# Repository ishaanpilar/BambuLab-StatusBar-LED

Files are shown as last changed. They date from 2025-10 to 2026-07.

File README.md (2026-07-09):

# Bambu Status Bar

**Version 2.0** — a full rewrite of the original firmware and repo
structure. See [CHANGELOG.md](CHANGELOG.md) for what changed.

A compact, ESP32-powered LED status bar for Bambu Lab 3D printers, with an
integrated purge-line holder — printed as one piece.

Real-time visual feedback for what the printer is doing: connecting,
homing/leveling, heating (with a live temperature-progress bar), printing
(with a live progress bar), paused, finished, or in an error state — all
read straight from the printer's own local MQTT status stream.

## Compatible printers

Any Bambu Lab printer with **LAN Mode (Developer Mode)** enabled:
X1 / X1C / X1E, P1P / P1S, A1 / A1 mini, H2D.

## Key features

- Visual states: WiFi/MQTT connecting, homing, bed leveling, nozzle
  heating, print progress, paused, finished, error (HMS)
- No hardcoded WiFi or printer credentials — first boot opens a setup
  portal (see [firmware/README.md](firmware/README.md))
- Single ESP32, short WS2812 LED strip, USB-powered from the printer's rear
  USB port
- [Flash straight from your browser](https://ishaanpilar.github.io/BambuLab-StatusBar-LED/) —
  no PlatformIO or Arduino IDE required
- Integrated purge-line holder, single-piece diagonal print
- PlatformIO firmware (with an Arduino IDE-compatible mirror) and a native
  unit-test suite for the core status logic
- Open source — contributions welcome

## Repo layout

```text
firmware/       ESP32 firmware (PlatformIO + Arduino IDE), unit tests
hardware/       3D print file, BOM, wiring/assembly docs
web-installer/  Browser-based flashing page (ESP Web Tools)
docs/           Troubleshooting and setup notes
```

## Quick start

1. Print [`hardware/PrintStatusBar_with_PurgeHolder.3mf`](hardware/PrintStatusBar_with_PurgeHolder.3mf)
   and wire it up — see [hardware/README.md](hardware/README.md).
2. Flash the firmware. Two options:
   - **Easiest:** plug the ESP32 into your computer and use the
     [browser installer](https://ishaanpilar.github.io/BambuLab-StatusBar-LED/)
     (Chrome/Edge desktop) — no software install needed.
   - **If you want to modify the firmware:** see
     [firmware/README.md](firmware/README.md) for PlatformIO/Arduino IDE
     instructions.
3. On first boot, connect to the `BambuStatusBar-Setup` WiFi network and
   fill in your WiFi + printer details in the captive portal.
4. Power it from your printer's internal USB port and mount it.

Having trouble? See [docs/troubleshooting.md](docs/troubleshooting.md).

## License

MIT — see [LICENSE](LICENSE)

## Contributing

Read [CONTRIBUTING.md](CONTRIBUTING.md). Issues and PRs welcome.

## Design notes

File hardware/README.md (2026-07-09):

# Hardware

A single-piece printed status bar with an integrated purge-line holder,
lit by a short WS2812 LED strip and driven by an ESP32.

## Parts

See [BOM.md](BOM.md).

## Print

- Model: [`PrintStatusBar_with_PurgeHolder.3mf`](PrintStatusBar_with_PurgeHolder.3mf)
- Prints diagonally in one go — no supports needed with the orientation
  baked into the file.
- Any 0.2mm-profile PLA/PETG print settings work; nothing exotic required.

## Wiring

| WS2812 strip pin | ESP32 |
|---|---|
| 5V | 5V (or VIN, if powering from the printer's USB) |
| GND | GND |
| DIN (data) | GPIO 5 (default — see `hw::kDataPin` in [`firmware/src/Config.h`](../firmware/src/Config.h)) |

- Default LED count is 13, matching the printed channel. If you resize the
  strip, update `hw::kNumLeds` in `firmware/src/Config.h` and reflash.
- The firmware caps LED draw at 850mA via `FastLED.setMaxPowerInMilliWatts`
  (`hw::kMaxMilliwatts`) so it stays within what a printer's rear USB port
  can safely supply — raise this only if you're powering the ESP32 from a
  separate supply rated for it.

## Assembly

1. Print the model and thread the LED strip into the channel, DIN end
   toward the ESP32.
2. Mount the ESP32 in the base — either M3 heat-set inserts + M3x6 screws,
   or double-sided tape.
3. Route the LED wires through the top hole to the ESP32.
4. Power the ESP32 from the printer's rear USB port with a short
   USB‑A → Micro‑USB/USB‑C cable.

See [`firmware/README.md`](../firmware/README.md) for flashing and
first-boot setup.

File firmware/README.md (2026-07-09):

# Firmware

ESP32 firmware that subscribes to a Bambu Lab printer's local (LAN-mode)
MQTT status stream and drives a WS2812 LED bar to reflect what it's doing —
connecting, heating, printing (with progress), paused, finished, or in an
error state.

Compatible with Bambu Lab's LAN-mode MQTT printers: X1/X1C/X1E, P1P/P1S,
A1/A1 mini, and H2D. LAN Mode (a.k.a. Developer Mode) must be enabled on the
printer — see [docs/troubleshooting.md](../docs/troubleshooting.md).

## Structure

- `src/` — the firmware, as a PlatformIO project (source of truth).
  - `main.cpp` — wiring/`setup()`/`loop()`.
  - `Config.h` — compile-time hardware config (LED pin/count/brightness).
  - `Provisioning.{h,cpp}` — WiFiManager captive portal + NVS storage for
    WiFi and printer identity (IP, serial, access code) — no secrets in
    source, no recompiling per printer.
  - `BambuMqttClient.{h,cpp}` — MQTT connect/reconnect/subscribe.
  - `PrinterState.{h,cpp}` — pure state-machine: MQTT payload → LED state +
    progress. No hardware dependency; unit tested (see below).
  - `LedController.{h,cpp}` — FastLED animations per state.
- `test/test_printer_state.cpp` — host-side unit tests for `PrinterState`.
- `arduino-ide/BambuStatusBar/BambuStatusBar.ino` — generated single-file
  mirror of `src/` for Arduino IDE users. Don't edit it directly — see
  below.
- `tools/generate_arduino_sketch.py` — regenerates the `.ino` mirror.

## Option A: PlatformIO (recommended)

1. [Install PlatformIO](https://platformio.org/install) (CLI or the VS Code
   extension).
2. From `firmware/`:
   ```
   pio run -e esp32dev          # build
   pio run -e esp32dev -t upload  # build + flash (board connected via USB)
   pio device monitor -b 115200   # serial log
   ```
3. Run the unit tests any time with `pio test -e native` (no hardware
   needed).

## Option B: Arduino IDE

1. Install the ESP32 board package and these libraries via Library
   Manager: **FastLED**, **PubSubClient**, **ArduinoJson** (v7), **WiFiManager**
   (by tzapu).
2. Open `arduino-ide/BambuStatusBar/BambuStatusBar.ino`.
3. Select your ESP32 board, then Upload.

If you change anything under `src/`, regenerate the mirror before
committing:
```
python3 tools/generate_arduino_sketch.py
```
CI fails the build if the mirror drifts from `src/`.

## First boot / setup

No credentials are hardcoded. On first boot (or after holding the BOOT
button for 3s at power-on), the ESP32 opens a WiFi access point named
`BambuStatusBar-Setup` with a captive portal to enter:

- Your WiFi network + password
- The printer's IP address
- The printer's serial number
- The printer's LAN-mode access code

These are saved to the ESP32's flash (NVS) and reused on every subsequent
boot. See [docs/troubleshooting.md](../docs/troubleshooting.md) for where to
find each of these on the printer, and what to check if it won't connect.

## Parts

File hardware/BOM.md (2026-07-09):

# Bill of Materials

| Qty | Part | Notes |
|-----|---|---|
| 1 | ESP32 dev board | e.g. ESP32 DevKit V1 (any dev board with a free GPIO + 5V/GND works) |
| 1 | WS2812 / WS2812B LED strip | 13 LEDs at the strip's native pitch, or trim/extend and update `NUM_LEDS` in firmware config |
| 1 | USB-A → Micro-USB or USB-C cable, short | Powers the ESP32 from the printer's rear USB port |
| 4 | M3 heat-set inserts | Optional — for a removable/serviceable mount |
| 4 | M3x6 screws | Optional, pairs with the heat-set inserts |
| — | Double-sided tape | Alternative to heat-set inserts for mounting |

See [README.md](README.md) for wiring and assembly.

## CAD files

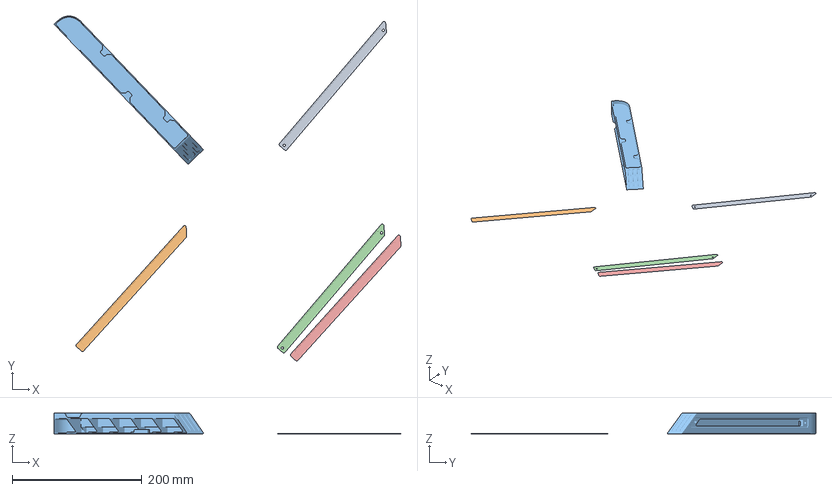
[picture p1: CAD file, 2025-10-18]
hardware/PrintStatusBar_with_PurgeHolder.3mf
534.2 x 531.2 x 32.0 mm
Diffuser.stl x 2
Diffuser No Holes.stl x 2
Purge Tray v6.stl

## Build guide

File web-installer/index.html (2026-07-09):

# Bambu Status Bar

Flash the firmware to your ESP32 straight from this page — no PlatformIO, no Arduino IDE, no config files to edit.

## 1. Connect your ESP32

Plug the ESP32 into this computer with a USB cable (the same one you'll use to power it from the printer works fine).

## 2. Install

Your browser doesn't support Web Serial. Open this page in Chrome or Edge on a desktop computer instead — Web Serial isn't available in Firefox, Safari, or on mobile. This page needs to be served over HTTPS (or localhost) to access USB devices. If you're seeing this on the published site, please open an issue (https://github.com/ishaanpilar/BambuLab-StatusBar-LED/issues). Works in Chrome / Edge on desktop.

## 3. Finish setup over WiFi

Once flashing completes, the ESP32 reboots and opens its own WiFi network to configure itself — no cables needed for this part:

1. On your phone or laptop, join the WiFi network named BambuStatusBar-Setup.
2. A setup page should open automatically (a "captive portal"). If it doesn't, open a browser and go to 192.168.4.1.
3. Enter your home WiFi details, plus your printer's IP address, serial number, and LAN access code, then save.

Not sure where to find your printer's IP/serial/access code, or the setup page isn't showing up? See the troubleshooting guide (https://github.com/ishaanpilar/BambuLab-StatusBar-LED/blob/main/docs/troubleshooting.md).

Want to modify the firmware instead? See the PlatformIO / Arduino IDE instructions (https://github.com/ishaanpilar/BambuLab-StatusBar-LED/blob/main/firmware/README.md) in the repo. · Bambu Status Bar on GitHub (https://github.com/ishaanpilar/BambuLab-StatusBar-LED)

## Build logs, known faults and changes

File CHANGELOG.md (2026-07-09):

# Changelog

## 2.0.0

Full rewrite of the original firmware and repo structure.

- Merged the two divergent original sketches (`Main_Progressbar_v5_web.ino`,
  `Main_Src_v4.ino`) into a single, defensively-parsed state machine
  (`firmware/src/PrinterState.cpp`) covering all Bambu Lab LAN-mode printers
  (X1/X1C/X1E, P1P/P1S, A1/A1 mini, H2D).
- Fixed: heating-progress bar was hardcoded to a 40–200°C range and broke on
  high-temp filaments (ABS/PC/PA); now scales to the printer's actual
  reported target temperature.
- Fixed: an MQTT buffer-size bug that could silently truncate large status
  payloads.
- Fixed: the ERROR (HMS) LED state had no way to recover once triggered;
  added proper recovery + same-packet hysteresis.
- Removed all hardcoded WiFi/MQTT credentials — first boot now opens a
  WiFiManager captive portal to configure WiFi and printer identity, no
  recompiling per printer.
- Added a native unit-test suite for the status logic (`pio test -e native`)
  and CI that builds the real firmware on every push.
- Added a browser-based installer (`web-installer/`, powered by ESP Web
  Tools) — flash over USB with no PlatformIO/Arduino IDE install required.
- Restructured the repo into `firmware/`, `hardware/`, `docs/`,
  `web-installer/` with docs that match reality.

## 1.x

The original, hand-built firmware — two independent Arduino sketches with
hardcoded credentials, still visible in git history prior to the 2.0.0
rewrite.

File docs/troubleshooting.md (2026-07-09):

# Troubleshooting

## Enabling LAN mode on the printer

This firmware talks to the printer's **local** MQTT broker over LAN — it
never touches Bambu's cloud. Every Bambu Lab printer needs this turned on
first:

1. On the printer's touchscreen: **Settings → Network → LAN Only Mode** (some
   firmware calls this **Developer Mode**) → enable it.
2. Once enabled, the screen shows an **Access Code** and the printer's
   **Serial Number** — you'll enter both into the status bar's setup portal.
3. Note the printer's **IP address** (same screen, or your router's DHCP
   client list).

If LAN mode isn't enabled, the ESP32 will connect to WiFi fine but MQTT will
never connect (the LEDs stay on the blue "connecting to printer" strobe
forever).

## The status bar never leaves the blue strobe (MqttConnecting)

- Confirm LAN Mode / Developer Mode is enabled on the printer (see above).
- Double-check the IP address, serial number, and access code entered during
  setup — re-enter them by holding the BOOT button for 3s at power-on to
  reopen the setup portal.
- The printer and the ESP32 must be on the same network/VLAN — MQTT here
  isn't routed through the cloud, so cross-subnet or guest-WiFi isolation
  will block it.
- The access code changes if LAN mode is toggled off and back on — re-check
  it on the printer's screen if it was recently re-enabled.

## Can't find the setup WiFi network

- Hold the BOOT button (GPIO 0) for 3 seconds while powering on to force the
  setup portal.
- Look for a WiFi network named `BambuStatusBar-Setup`, connect to it, and a
  captive portal page should open automatically (or browse to `192.168.4.1`).
- The portal times out after 3 minutes with no activity; power-cycle to
  retry.

## LEDs are dim, flickering, or the ESP32 browns out

- The firmware limits LED draw to 850mA (`hw::kMaxMilliwatts` in
  `firmware/src/Config.h`) to stay within a printer USB port's budget. If
  you've lengthened the strip, either lower `hw::kBrightness` or power the
  ESP32 from a separate 5V supply instead of the printer's USB port.

## Only some fields update (progress bar doesn't move, heating never shows, etc.)

- Different Bambu models/firmware report slightly different fields over
  MQTT — this firmware is written defensively around that (see
  `firmware/src/PrinterState.cpp`), but if you find a genuine gap on your
  model, open an issue with a sample MQTT payload (`mosquitto_sub` against
  the printer's broker with TLS/insecure flags, topic
  `device/<serial>/report`) and we'll extend the parser.

## Nothing shows up at all / status bar looks off

- Reflash and watch the serial monitor at 115200 baud during boot — WiFi and
  MQTT connection steps are logged there.
- Confirm the LED strip's DIN wire is on the pin defined by `hw::kDataPin`
  and that GND is shared between the strip and the ESP32.

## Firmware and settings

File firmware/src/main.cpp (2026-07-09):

#include <Arduino.h>

#include "BambuMqttClient.h"
#include "Config.h"
#include "LedController.h"
#include "PrinterState.h"
#include "Provisioning.h"

LedController ledController;
Provisioning provisioning;
BambuMqttClient mqttClient;
PrinterStateMachine printerState;

namespace {
constexpr unsigned long kFrameIntervalMs = 33;  // ~30fps animation refresh
unsigned long lastFrameMs = 0;
}  // namespace

void onMqttPayload(ArduinoJson::JsonVariantConst printObj, unsigned long nowMs) {
  printerState.update(printObj, nowMs);
}

void setup() {
  Serial.begin(115200);
  ledController.begin();

  Serial.print(F("Bambu Status Bar v"));
  Serial.println(kFirmwareVersion);
  provisioning.begin();
}

void loop() {
  unsigned long now = millis();

  if (!provisioning.isReady()) {
    provisioning.tick();
    ledController.render(provisioning.isPortalActive() ? SystemState::Provisioning : SystemState::WifiConnecting,
                          printerState.telemetry(), now);
    return;
  }

  static bool mqttConfigured = false;
  if (!mqttConfigured) {
    const auto& cfg = provisioning.printerConfig();
    mqttClient.begin(cfg.ip, mqtt_cfg::kPort, mqtt_cfg::kUsername, cfg.accessCode, cfg.serial);
    mqttClient.setPayloadHandler(onMqttPayload);
    mqttConfigured = true;
    Serial.println(F("Provisioned — connecting to printer MQTT..."));
  }

  mqttClient.ensureConnected(now);
  mqttClient.loop();

  SystemState renderState = mqttClient.connected() ? printerState.state() : SystemState::MqttConnecting;

  if (now - lastFrameMs >= kFrameIntervalMs) {
    lastFrameMs = now;
    ledController.render(renderState, printerState.telemetry(), now);
  }
}

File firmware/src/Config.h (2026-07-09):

#pragma once

// Keep in sync with the repo-root VERSION file.
constexpr const char* kFirmwareVersion = "2.0.0";

// ===============================
// Hardware configuration
//
// These are compile-time because they describe how the board is physically
// wired — they don't change without re-soldering. WiFi/printer identity is
// runtime-configurable instead; see Provisioning.h.
// ===============================
namespace hw {
constexpr int kDataPin = 5;
constexpr int kNumLeds = 13;
constexpr uint8_t kBrightness = 64;
constexpr uint16_t kMaxMilliwatts = 850;
}  // namespace hw

// ===============================
// Provisioning / NVS storage keys
// ===============================
namespace provisioning_cfg {
constexpr const char* kPrefsNamespace = "bambu";
constexpr const char* kKeyPrinterIp = "ip";
constexpr const char* kKeyPrinterSerial = "serial";
constexpr const char* kKeyAccessCode = "code";

// Hold this pin low (BOOT button on most ESP32 dev boards) for
// kResetHoldMs at power-on to force re-provisioning.
constexpr int kResetButtonPin = 0;
constexpr unsigned long kResetHoldMs = 3000;

// If WiFi hasn't connected within this many attempts, fall back to the
// captive portal instead of hanging forever.
constexpr int kWifiConnectMaxAttempts = 40;  // ~20s at 500ms/attempt
constexpr unsigned long kPortalTimeoutMs = 180000;  // 3 minutes
}  // namespace provisioning_cfg

// ===============================
// MQTT
// ===============================
namespace mqtt_cfg {
constexpr int kPort = 8883;
constexpr const char* kUsername = "bblp";
constexpr unsigned long kReconnectIntervalMs = 3000;
}  // namespace mqtt_cfg

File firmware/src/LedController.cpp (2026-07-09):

#include "LedController.h"

namespace {
constexpr CRGB kPrintingOnColor = CRGB::Green;
constexpr CRGB kPrintingOffColor = CRGB::Red;

// Finished plays a brief twinkle before settling solid — matches the
// original firmware's "job just finished" flourish.
constexpr unsigned long kFinishedTwinkleStartMs = 2000;
constexpr unsigned long kFinishedTwinkleEndMs = 30000;
}  // namespace

void LedController::begin() {
  FastLED.addLeds<WS2812B, hw::kDataPin, GRB>(leds_, hw::kNumLeds);
  FastLED.setMaxPowerInMilliWatts(hw::kMaxMilliwatts);
  FastLED.setBrightness(hw::kBrightness);
  FastLED.clear(true);
}

void LedController::setAll(CRGB color) {
  fill_solid(leds_, hw::kNumLeds, color);
  FastLED.show();
}

void LedController::renderProgressBar(CRGB onColor, CRGB offColor, uint8_t percent) {
  int onLeds = static_cast<int>(hw::kNumLeds * (percent / 100.0f) + 0.5f);
  for (int i = 0; i < hw::kNumLeds; i++) {
    leds_[i] = (i < onLeds) ? onColor : offColor;
  }
  FastLED.show();
}

void LedController::renderHeating(uint8_t percent) {
  int lit = static_cast<int>(hw::kNumLeds * (percent / 100.0f) + 0.5f);
  fill_solid(leds_, hw::kNumLeds, CRGB(30, 0, 0));
  for (int i = 0; i < lit; i++) {
    leds_[i] = CRGB(map(i, 0, max(lit - 1, 1), 64, 255), map(i, 0, max(lit - 1, 1), 21, 85), 0);
  }
  FastLED.show();
}

void LedController::renderComet(CRGB color, unsigned long nowMs, uint16_t stepMs) {
  static int pos = 0;
  static int dir = 1;
  static unsigned long lastStep = 0;
  if (nowMs - lastStep > stepMs) {
    lastStep = nowMs;
    pos += dir;
    if (pos >= hw::kNumLeds - 1) dir = -1;
    if (pos <= 0) dir = 1;
  }
  fill_solid(leds_, hw::kNumLeds, CRGB::Black);
  for (int tail = 0; tail < 4; tail++) {
    int idx = pos - tail;
    if (idx >= 0 && idx < hw::kNumLeds) leds_[idx] = color / (1 << tail);
  }
  FastLED.show();
}

void LedController::renderWave(unsigned long nowMs, uint8_t hue) {
  float phase = nowMs * 0.002f;
  for (int i = 0; i < hw::kNumLeds; i++) {
    uint8_t v = sin8(static_cast<uint8_t>(i * 16 + phase * 40));
    leds_[i] = CHSV(hue, 255, v);
  }
  FastLED.show();
}

void LedController::renderPulse(CRGB color, unsigned long nowMs, uint16_t periodMs) {
  uint16_t t = nowMs % periodMs;
  float phase = (t < periodMs / 2) ? (t / static_cast<float>(periodMs / 2))
                                    : (1.0f - (t - periodMs / 2) / static_cast<float>(periodMs / 2));
  CRGB col = color;
  col.nscale8(static_cast<uint8_t>(32 + phase * 223));
  fill_solid(leds_, hw::kNumLeds, col);
  FastLED.show();
}

void LedController::renderStrobe(CRGB color, unsigned long nowMs, uint16_t onMs, uint16_t offMs) {
  uint16_t t = nowMs % (onMs + offMs);
  fill_solid(leds_, hw::kNumLeds, t < onMs ? color : CRGB::Black);
  FastLED.show();
}

void LedController::renderFinished(unsigned long nowMs, unsigned long finishedAtMs) {
  unsigned long elapsed = nowMs - finishedAtMs;
  if (elapsed < kFinishedTwinkleStartMs || elapsed > kFinishedTwinkleEndMs) {
    setAll(kPrintingOnColor);
    return;
  }
  for (int i = 0; i < hw::kNumLeds; i++) {
    unsigned long period = 500 + (i * 421) % 500;
    leds_[i] = CRGB(0, 255 * (nowMs % period < period / 2), 0);
  }
  FastLED.show();
}

void LedController::render(SystemState state, const PrinterTelemetry& telemetry, unsigned long nowMs) {
  switch (state) {
    case SystemState::Provisioning:
      renderPulse(CRGB::Blue, nowMs, 2000);
      break;
    case SystemState::WifiConnecting:
      renderWave(nowMs, 160);  // blue
      break;
    case SystemState::MqttConnecting:
      renderStrobe(CRGB::Blue, nowMs, 100, 100);
      break;
    case SystemState::Idle:
      renderPulse(CRGB::Green, nowMs, 3000);
      break;
    case SystemState::Homing:
      renderStrobe(CRGB::Blue, nowMs, 300, 300);
      break;
    case SystemState::Leveling:
      renderComet(CRGB::Magenta, nowMs, 120);
      break;
    case SystemState::Preparing:
      renderComet(CRGB::Yellow, nowMs, 80);
      break;
    case SystemState::Heating:
      renderHeating(telemetry.progressPercent);
      break;
    case SystemState::Printing:
      renderProgressBar(kPrintingOnColor, kPrintingOffColor, telemetry.progressPercent);
      break;
    case SystemState::Paused:
      renderPulse(CRGB(255, 170, 0), nowMs, 1600);
      break;
    case SystemState::Finished:
      renderFinished(nowMs, telemetry.finishedAtMs);
      break;
    case SystemState::Error:
      renderStrobe(CRGB::Red, nowMs, 150, 150);
      break;
  }
}

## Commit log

2025-10-20 Update README title for Bambu Lab Printers
2026-07-09 Rewrite firmware and repo structure for v2.0
    Merges the two divergent original sketches into one defensively-parsed
    state machine covering all Bambu Lab LAN-mode printers, fixes the
    heating-range, MQTT-buffer, and error-recovery bugs, replaces hardcoded
    credentials with a WiFiManager captive portal, adds native unit tests
    and CI, restructures the repo into firmware/hardware/docs, and adds a
    browser-based ESP Web Tools installer so flashing needs no toolchain.
    [PrintStatusBar_with_PurgeHolder.3mf]
